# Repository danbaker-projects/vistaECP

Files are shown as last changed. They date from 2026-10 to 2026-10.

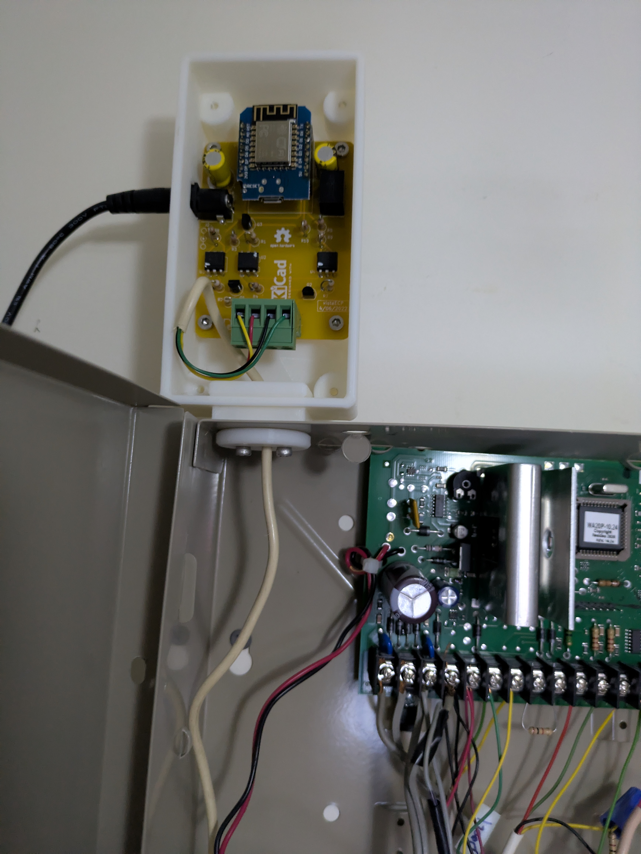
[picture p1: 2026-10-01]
kicad/vistaECP/vistaECP-mounted-on-honeywell-panel.jpg

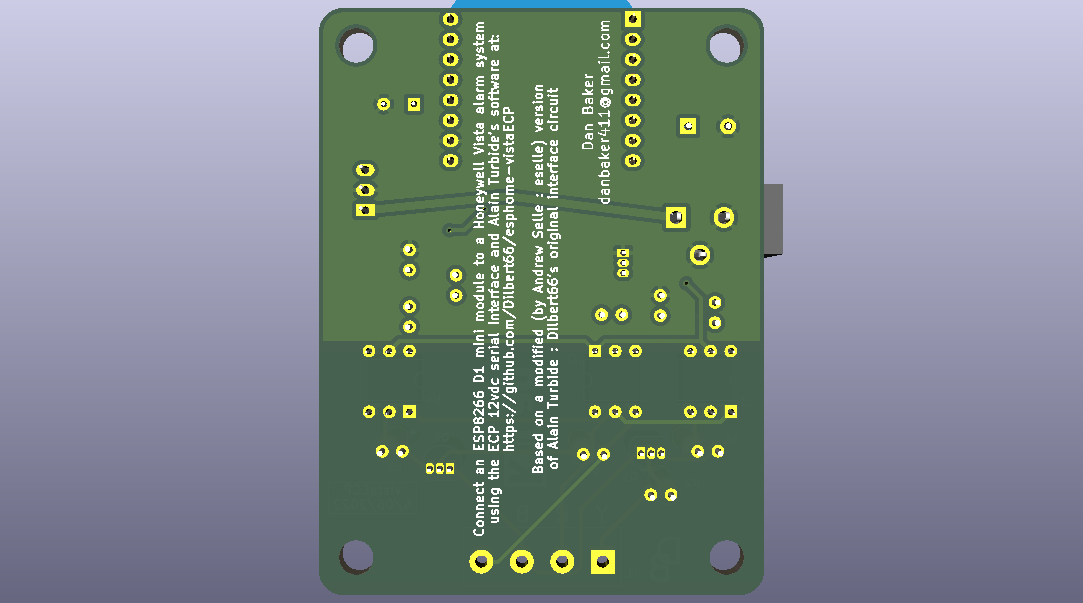
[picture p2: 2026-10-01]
kicad/vistaECP/vistaECP-Back-2026-09-30.png

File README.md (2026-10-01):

ECP 4-wire interface for Honeywell (Ademco) Alarm Panels such as Vista 20P

This circuit board allows you to connect an ESP8266 D1 mini module
to a Honeywell Vista alarm system
using the ECP 12vdc serial interface and Alain Turbide's software at:
https://github.com/Dilbert66/esphome-vistaECP.

vistaECP-mounted-on-honeywell-panel

This involves soldering parts to a printed circuit board, so be very careful how you pronounce the word solder.
Either the 'l' is silent and the 'r' is pronounced, or maybe it's the other way around. One is the good way, and the other way is stupid and evil.
It's like those mindless jerks who insist on breaking their eggs on the wrong end. Gulliver can tell you more about that.

Where was I????? Oh, yeah...

This circuit is based on a modified (by Andrew Selle : eselle) version of Alain Turbide : Dilbert66's original interface circuit

I've been using it for several years to interface my Honeywell system to Home Assistant using esphome-vistaECP by Alain Turbide. (thanks Dilbert66)

I'm including all Kicad design files and the Gerber files to make the PCB,
as well as the FreeCAD design files and .stl models I used to make a 3d-printed case and a bushing to connect it through a knockout on the alarm panel.

In the kicad directory there are pictures of the front and back of the board
and a PDF of the schematic if you don't want to install Kicad to view them.

There is a zip file with all gerbers inside. You can send this file to (probably) and good PCB fab shop to make your board(s).

This board uses opto-isolators on all lines to/from the Honeywell panel, and soldered through-hole components.

For all software information, refer to https://github.com/Dilbert66/esphome-vistaECP

I probably won't be maintaining this, just making it available for esphome-vistaECP users.
It's been very reliable for me for several years now, and I hope you find it useful.

I started work on a board supporting either a D1 mini board or an ESP32-WROOM-32 module, but never finished it because
this version works so well for me.

Dan Baker

vistaECP-Front-2026-09-30

vistaECP-Back-2026-09-30

[vistaECP-Schematic.pdf](https://github.com/user-attachments/files/32884098/vistaECP-Schematic.pdf)

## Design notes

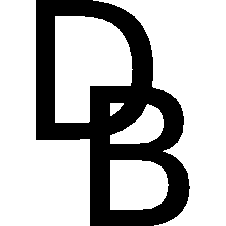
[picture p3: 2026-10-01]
kicad/vistaECP/dan-kicad/DB03-226x226.png

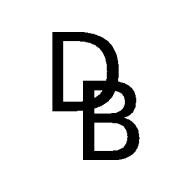
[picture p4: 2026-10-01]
kicad/vistaECP/dan-kicad/DB03small-192x192.png

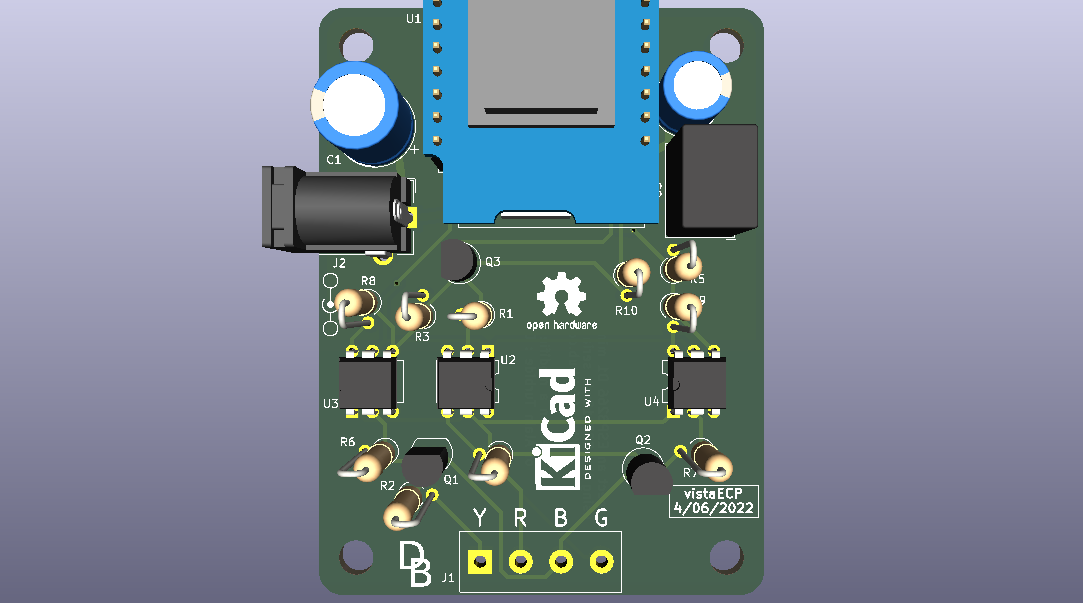
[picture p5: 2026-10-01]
kicad/vistaECP/vistaECP-Front-2026-09-30.png

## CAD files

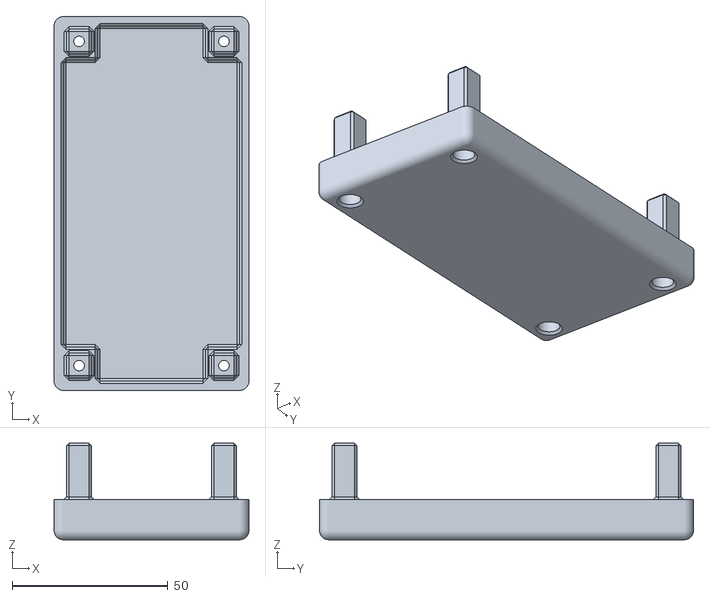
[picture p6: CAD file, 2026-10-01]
freecad/vistaECP/vistaECP-Lid.stl
62.5 x 120.0 x 31.0

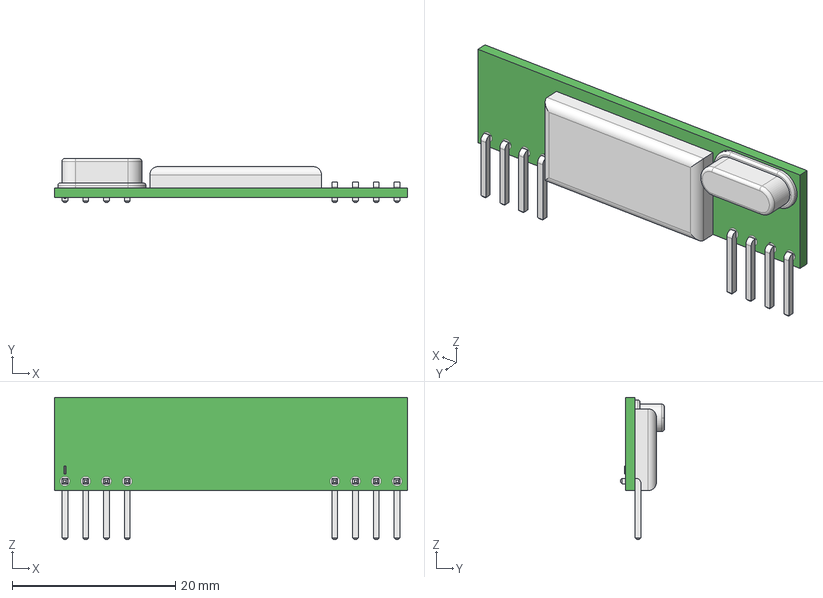
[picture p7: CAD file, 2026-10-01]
kicad/vistaECP/3dModels/RXB6_RF_Receiver_Module.step
43.2 x 5.40 x 17.4 mm

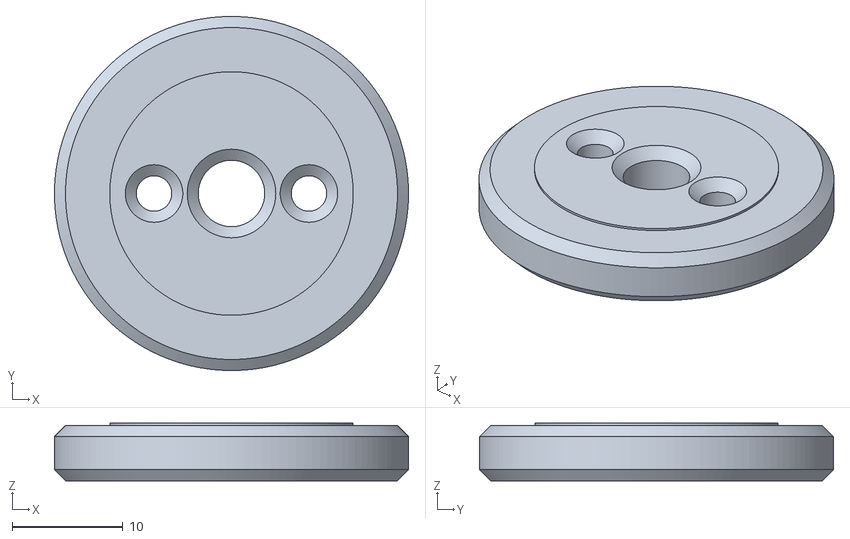
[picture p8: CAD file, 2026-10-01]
freecad/vistaECP/vistaECP-BushingMountingPlate.stl
32.0 x 32.0 x 5.20

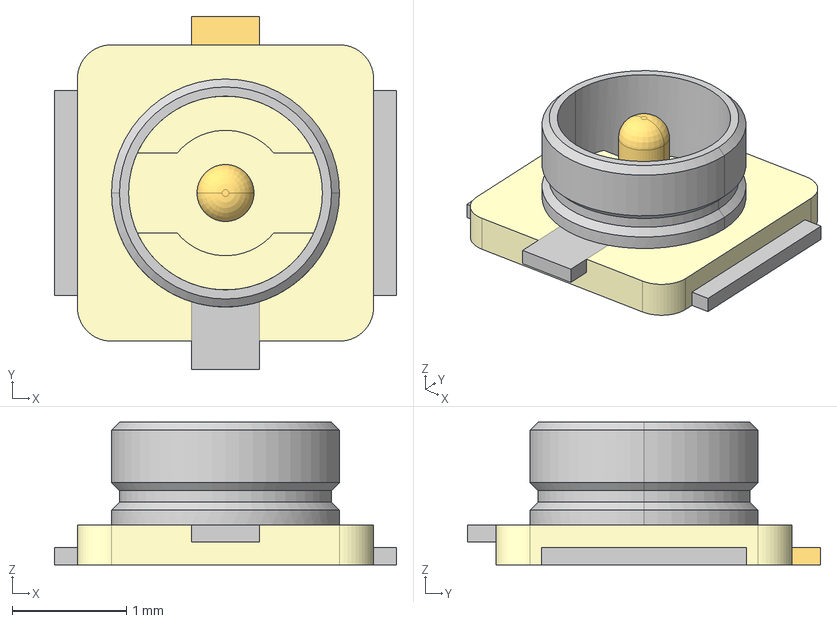
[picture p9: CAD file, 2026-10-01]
kicad/vistaECP/3dModels/U.FL-R-SMT-1.step
3.00 x 3.10 x 1.25 mm

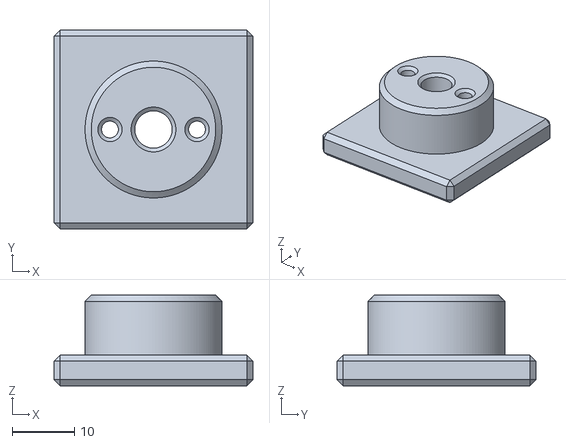
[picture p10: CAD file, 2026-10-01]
freecad/vistaECP/vistaECP-CableBushing.stl
32.0 x 32.0 x 14.6

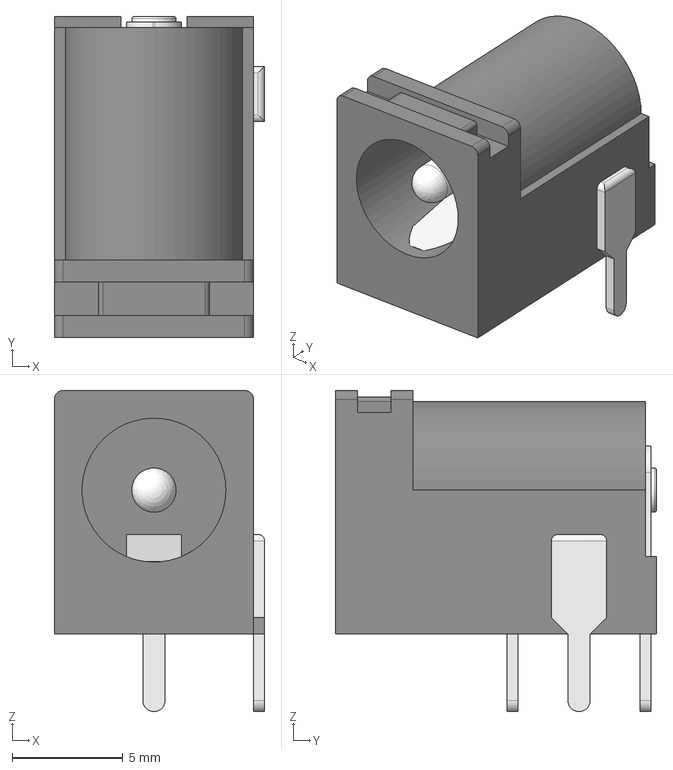
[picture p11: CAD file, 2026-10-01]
kicad/vistaECP/3dModels/BarrelJack-102AH_Horizontal-kicad.step
9.50 x 14.5 x 14.5 mm

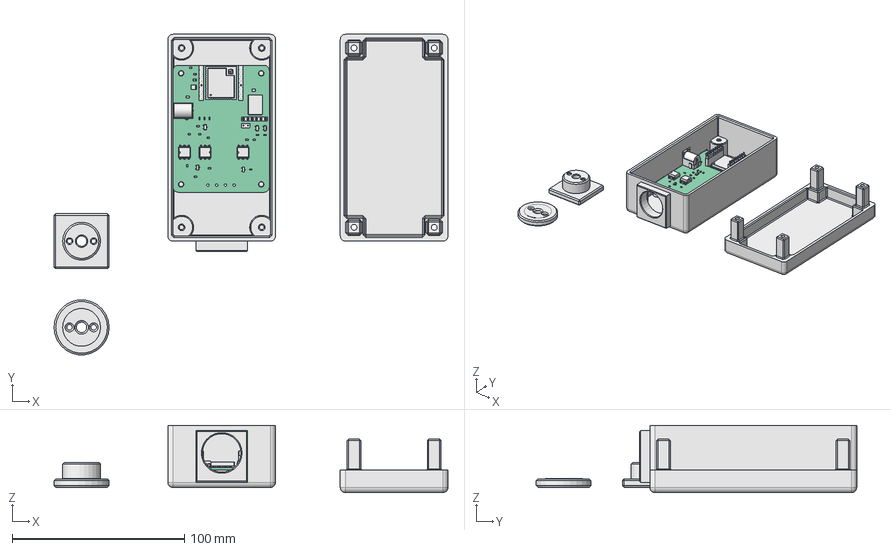
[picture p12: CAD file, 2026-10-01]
freecad/vistaECP/vistaECP.FCStd
228.5 x 185.9 x 39.0 mm
Back
BushingMountingPlate
Lid
CableBushing
Pcb_6cbc
R1_R_0603_1608Metric_0000624cd42b x 17
U2_DIP-6_W7.62mm_0000624cd506 x 3
U1_PinHeader_1x08_P254mm_Vertical_0000624cf981[2] x 2
U1_PinSocket_1x08_P254mm_Vertical_0000624cf981[4] x 2
C1_R_0805_2012Metric_0000624df353 x 3
J2_BarrelJack-102AH_Horizontal-kicad_0000624df46f[2]
U5_Converter_DCDC_RECOM_R_78E_05_THT_0000624df947
J4_PinSocket_1x06_P254mm_Vertical_8a307bb477fb
Q4_SOT_23_1b00d17437e9 x 5
U6_ESP32-WROOM-32U_fb7817eb1e1f
J3_PinHeader_1x02_P254mm_Vertical_d3f82129dbab
C5_R_1210_3225Metric_abed3213256f

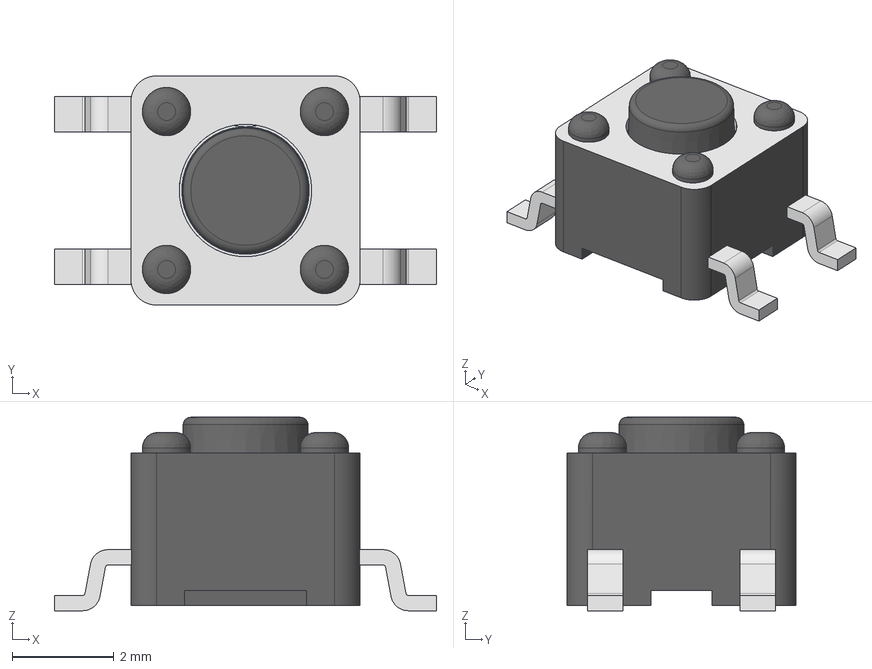
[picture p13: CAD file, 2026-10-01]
kicad/vistaECP/3dModels/Pushbutton_SMD_TL3305A.step
7.50 x 4.50 x 3.80 mm

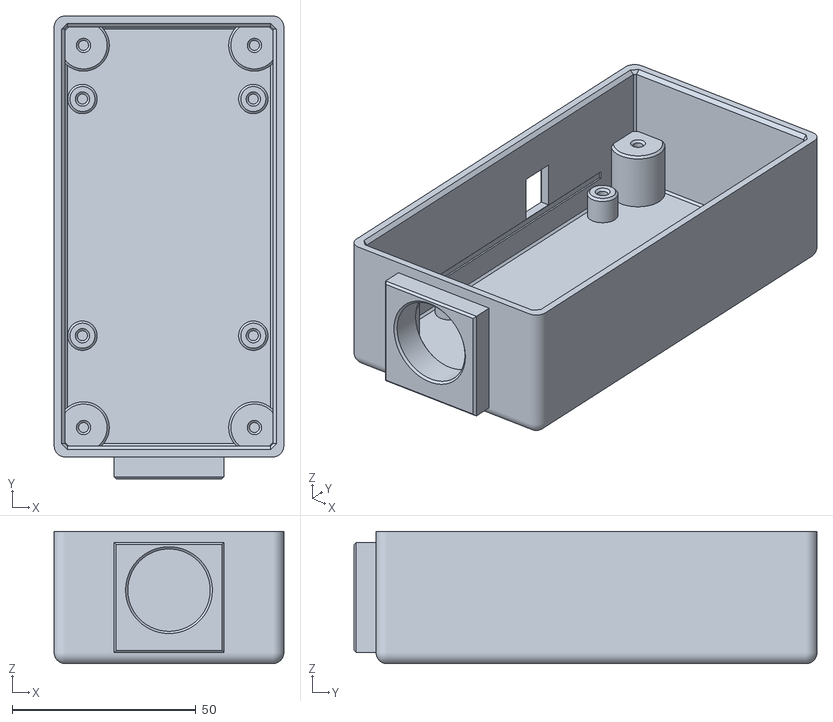
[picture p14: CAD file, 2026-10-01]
freecad/vistaECP/vistaECP-Back.stl
62.5 x 126.0 x 36.0

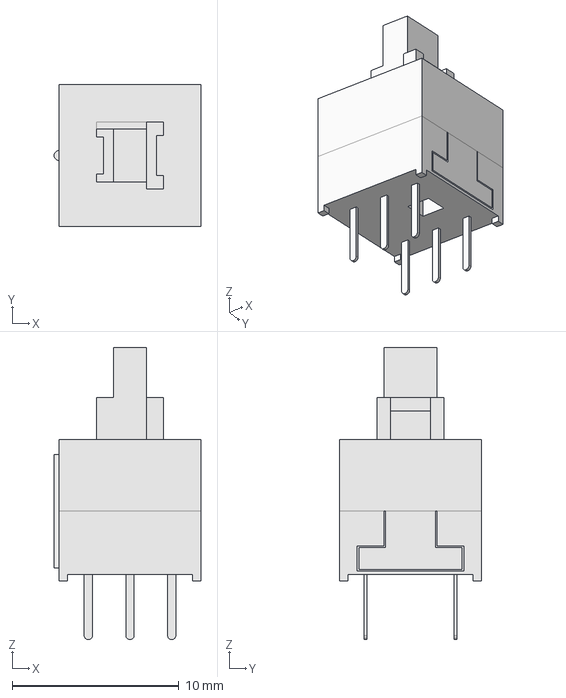
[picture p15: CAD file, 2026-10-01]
kicad/vistaECP/3dModels/Pushbutton_DPDT_Latching_8.5mm-kicad.fcstd
8.80 x 8.50 x 17.5 mm

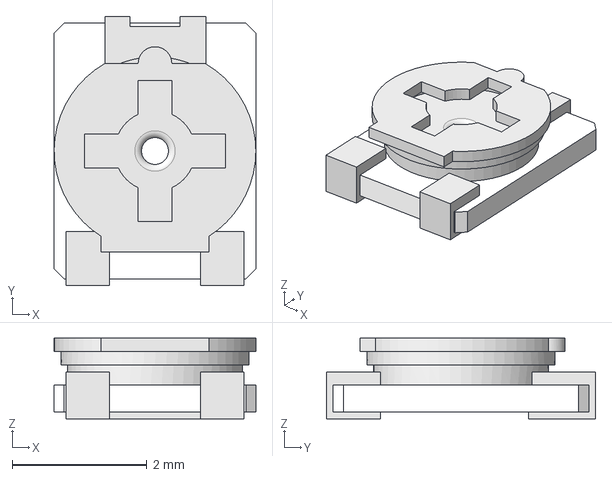
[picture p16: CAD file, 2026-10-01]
kicad/vistaECP/3dModels/Trimpot_3_8mmx3_6mm_TC33X_2_103E.step
3.00 x 4.00 x 1.20 mm

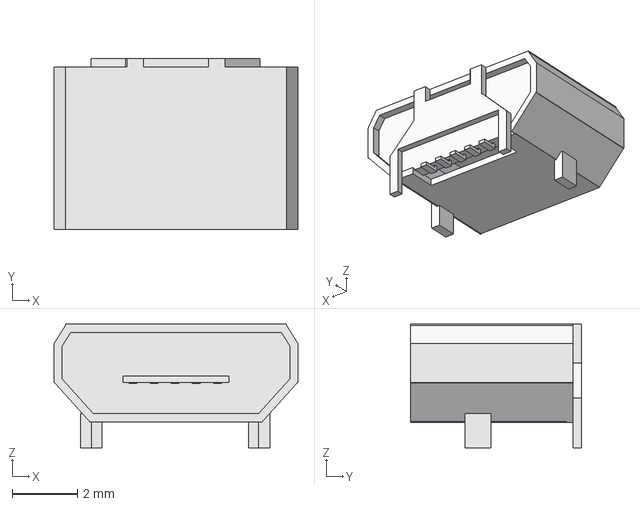
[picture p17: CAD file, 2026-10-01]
kicad/vistaECP/3dModels/USB_Micro_B_Amphenol_10103594_0001LF_Horizontal-kicad.fcstd
7.50 x 5.25 x 3.80 mm

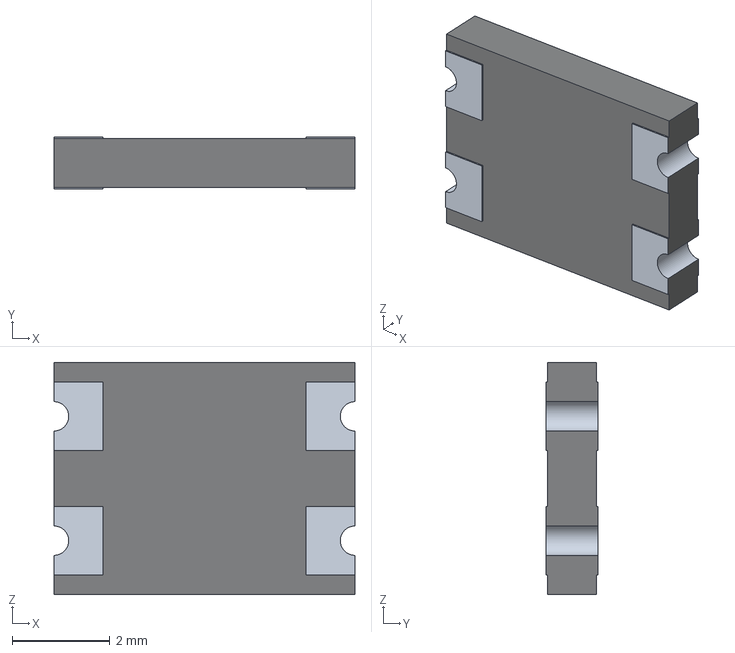
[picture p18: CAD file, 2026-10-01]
kicad/vistaECP/3dModels/CD-HD0x_3d.stp
6.15 x 1.07 x 4.75 mm

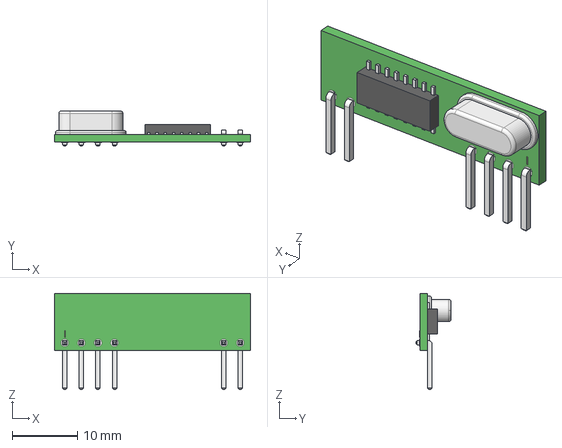
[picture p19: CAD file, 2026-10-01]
kicad/vistaECP/3dModels/RXB12_RF_Receiver_Module.step
30.0 x 5.40 x 14.7 mm

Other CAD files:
kicad/vistaECP/3dModels/TL3305AFxxxxG.stp
kicad/vistaECP/3dModels/RF-RX-RXB6.fcstd
kicad/vistaECP/3dModels/Trimpot_3.8mmx3.6mm_TC33X-2-103E.fcstd
kicad/vistaECP/3dModels/kicad-SMD-Diode-b340.fcstd
kicad/vistaECP/3dModels/BarrelJack-102AH_Horizontal-kicad.fcstd
kicad/vistaECP/3dModels/Pushbutton_DPDT_Latching_8.5mm.step
kicad/vistaECP/3dModels/Pushbutton_SMD_TL3305A.fcstd
kicad/vistaECP/3dModels/RF-RX-RXB12.fcstd
kicad/vistaECP/3dModels/RFB12-RF_Receiver_Module.step
kicad/vistaECP/3dModels/Schottky-Diode-B340.step
kicad/vistaECP/3dModels/U.FL-R-SMT-1.stp
kicad/vistaECP/3dModels/USB_Micro_B_Amphenol_10103594_0001LF_Horizontal.step

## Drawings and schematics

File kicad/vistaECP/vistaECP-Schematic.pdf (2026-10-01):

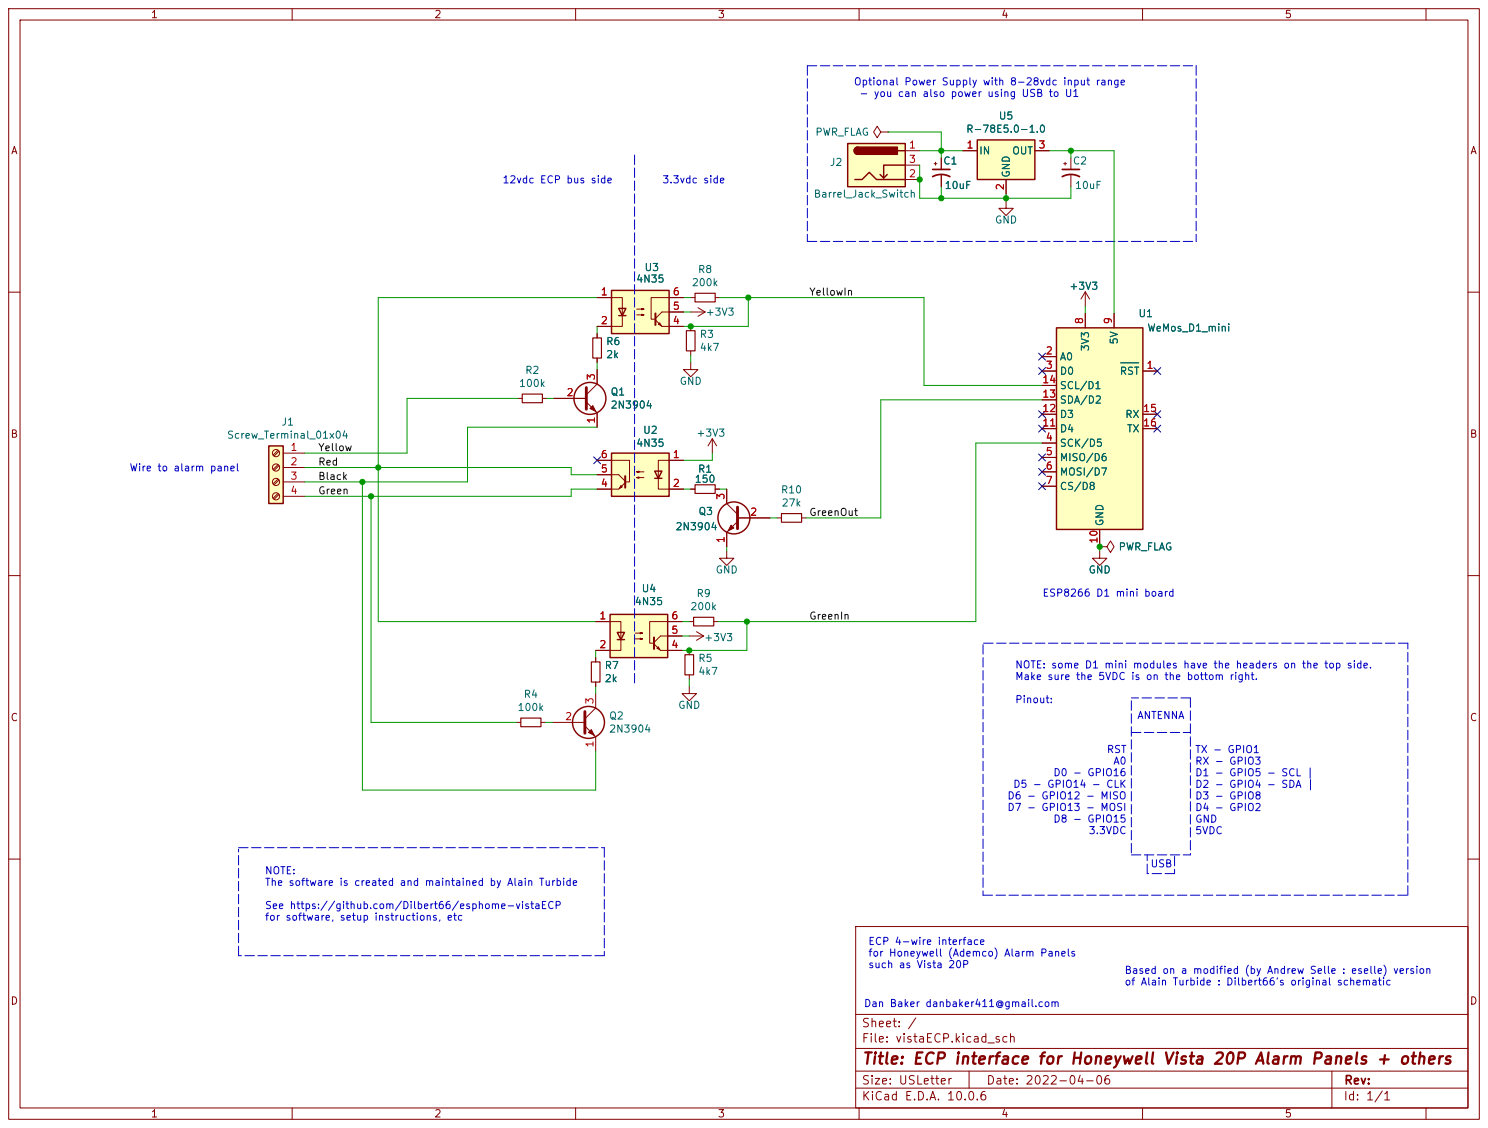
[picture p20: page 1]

8 5V 9 GND 10 D4 11 D3 12 SDA/D2 13 SCL/D1 14 RX 15

TX - GPIO1 RX - GPIO3 D1 - GPIO5 - SCL | D2 - GPIO4 - SDA | D3 - GPIO8 D4 - GPIO2 GND

3.3VDC NOTE: The software is created and maintained by Alain Turbide See https://github.com/Dilbert66/esphome-vistaECP

ECP 4-wire interface
for Honeywell (Ademco) Alarm Panels
such as Vista 20P

of Alain Turbide : Dilbert66's original schematic

Dan Baker danbaker411@gmail.com
Sheet: /
File: vistaECP.kicad_sch
Title: ECP interface for Honeywell Vista 20P Alarm Panels + others

Size: USLetter | Rev:
KiCad E.D.A. 10.0.6 | Id: 1/1

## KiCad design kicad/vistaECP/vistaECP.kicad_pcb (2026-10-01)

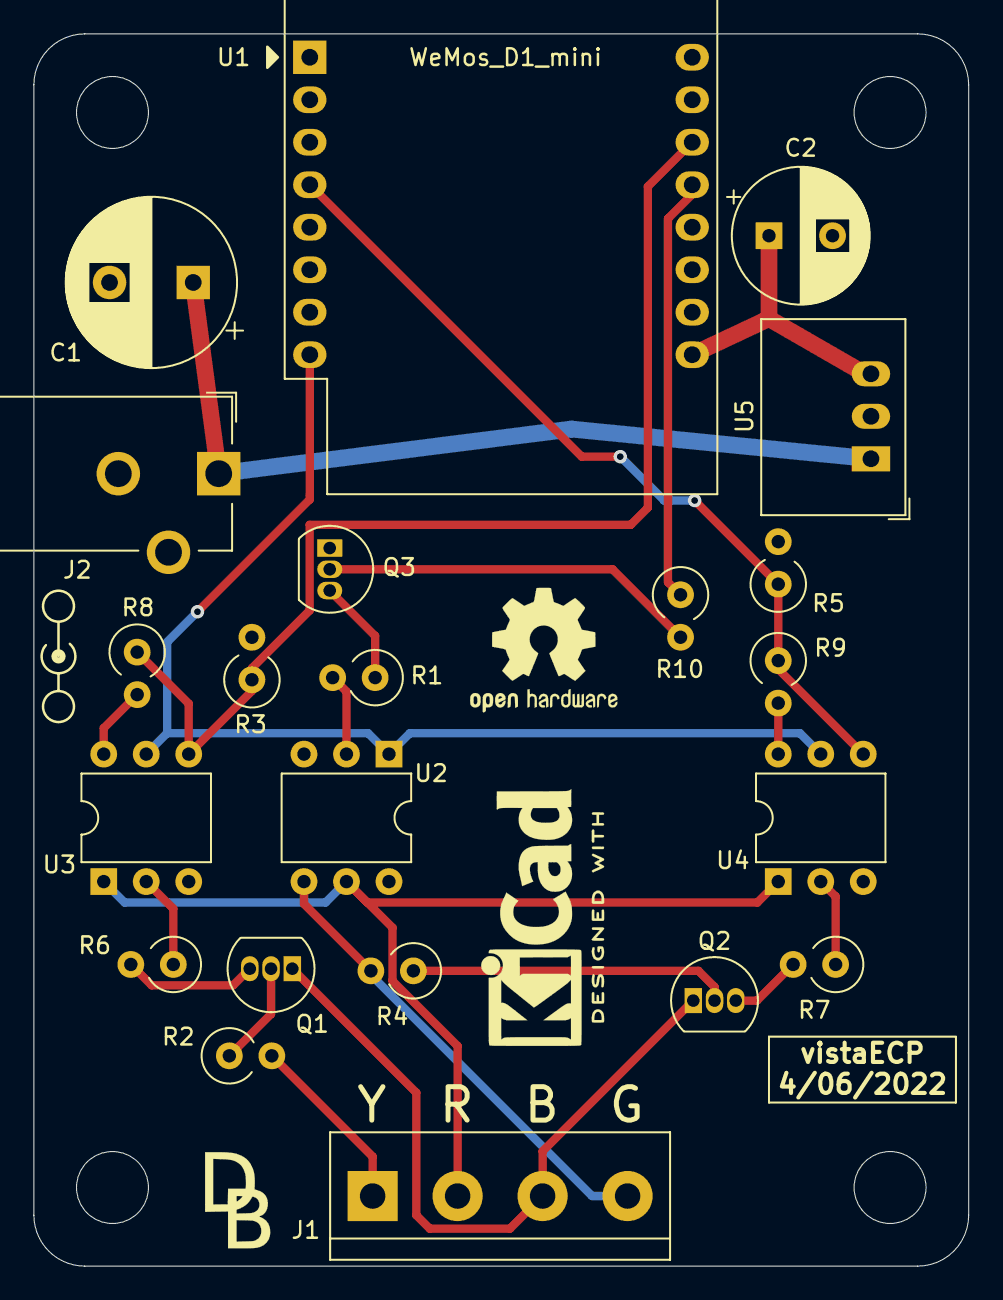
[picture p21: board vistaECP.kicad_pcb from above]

Board: 2 copper layers, 55.9 x 73.7 mm, 22 parts (0 on the bottom side), 22 nets.

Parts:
C1: 10uF; CP_Radial_D10.0mm_P5.00mm
C2: 10uF; CP_Radial_D8.0mm_P3.80mm
J1: Screw_Terminal_01x04; TerminalBlock_bornier-4_P5.08mm
J2: Barrel_Jack_Switch; BarrelJack_CUI_PJ-102AH_Horizontal
Q1, Q2, Q3: 2N3904; TO-92_Inline
R1: 150; R_Axial_DIN0309_L9.0mm_D3.2mm_P2.54mm_Vertical
R2, R4: 100k; R_Axial_DIN0309_L9.0mm_D3.2mm_P2.54mm_Vertical
R3, R5: 4k7; R_Axial_DIN0309_L9.0mm_D3.2mm_P2.54mm_Vertical
R6, R7: 2k; R_Axial_DIN0309_L9.0mm_D3.2mm_P2.54mm_Vertical
R8, R9: 200k; R_Axial_DIN0309_L9.0mm_D3.2mm_P2.54mm_Vertical
R10: 27k; R_Axial_DIN0309_L9.0mm_D3.2mm_P2.54mm_Vertical
U1: WeMos_D1_mini; WEMOS_D1_mini_light
U2, U3, U4: 4N35; DIP-6_W7.62mm
U5: R-78E5.0-1.0; Converter_DCDC_RECOM_R-78E-0.5_THT

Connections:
+3V3: U1.8, U2.1, U3.5, U4.5
/Black: J1.3, Q1.1, Q2.1
/Green: J1.4, R4.2, U2.4
/GreenIn: R5.1, R9.1, U1.4, U4.4
/GreenOut: R10.1, U1.13
/Red: J1.2, U2.5, U3.1, U4.1
/Yellow: J1.1, R2.2
/YellowIn: R3.1, R8.1, U1.14, U3.4
GND: C1.2, C2.2, J2.2, J2.3, Q3.1, R3.2, R5.2, U1.10, U5.2
unnamed: C1.1, J2.1, U5.1
unnamed: C2.1, U1.9, U5.3
unnamed: Q1.2, R2.1
unnamed: Q1.3, R6.2
unnamed: Q2.2, R4.1
unnamed: Q2.3, R7.2
unnamed: Q3.2, R10.2
unnamed: Q3.3, R1.1
unnamed: R1.2, U2.2
unnamed: R6.1, U3.2
unnamed: R7.1, U4.2
unnamed: R8.2, U3.6
unnamed: R9.2, U4.6

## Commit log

2026-10-01 Files for WiFi interface to Honeywell Vista Alarm Panels for esphome-vistaECP
    [BarrelJack-102AH_Horizontal-kicad.fcstd, BarrelJack-102AH_Horizontal-kicad.step, CD-HD0x_3d.stp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]
2026-10-01 added picture of board installed on panel in 3d printed box
2026-10-01 Update README.md
    Added pictures and link to pdf schematic
